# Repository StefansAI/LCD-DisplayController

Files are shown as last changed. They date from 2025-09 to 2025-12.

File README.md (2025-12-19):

<h1 style="text-align: center;">LCD-DisplayController</h1>
<h2 style="text-align: center;">Controller board to display 2 and 4 lines on LCD modules</h2>
<br>
<div style="text-align: center;">
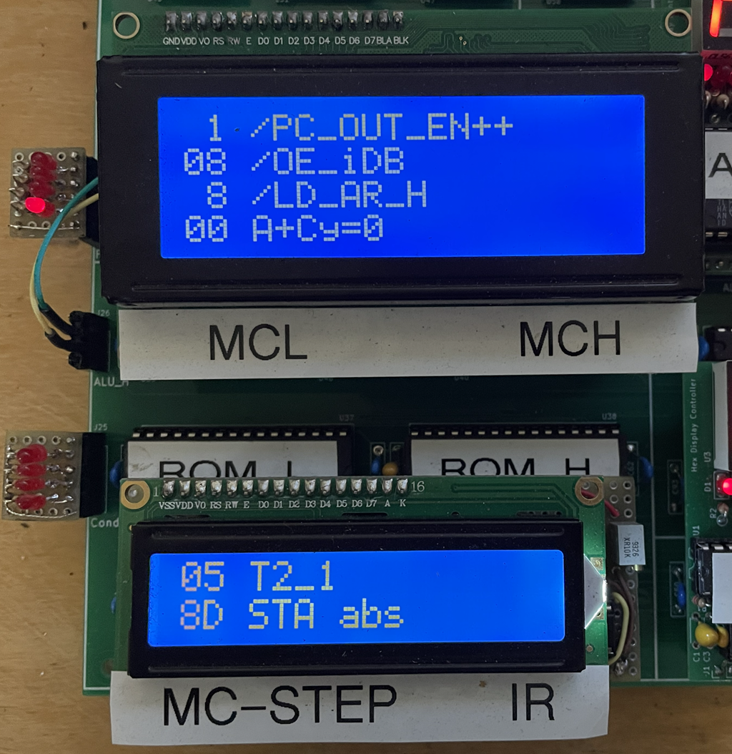
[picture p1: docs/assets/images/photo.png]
  
</div>
<br>
The <a href="https://github.com/StefansAI/TTL-6510-Computer">TTL 6510 computer.</a> was designed with connectors for plugging in <a href="https://github.com/StefansAI/HexDisplayController">HexDisplayControllers</a> for displaying register contents etc. Originally these hex displays were used for the micro code steps, instruction register and micro code outputs. Instead of looking up the meaning of instruction codes or the micro code bit group meanings, I decided to switch to multi line displays I had laying around.<br>
The instruction code and micro step counter can be displayed on a 2 line LCD text display module, while the 4 micro step signal groups can better be displayed on a 4 line LCD text display module. 
<br>
<br>
<div style="text-align: center;">
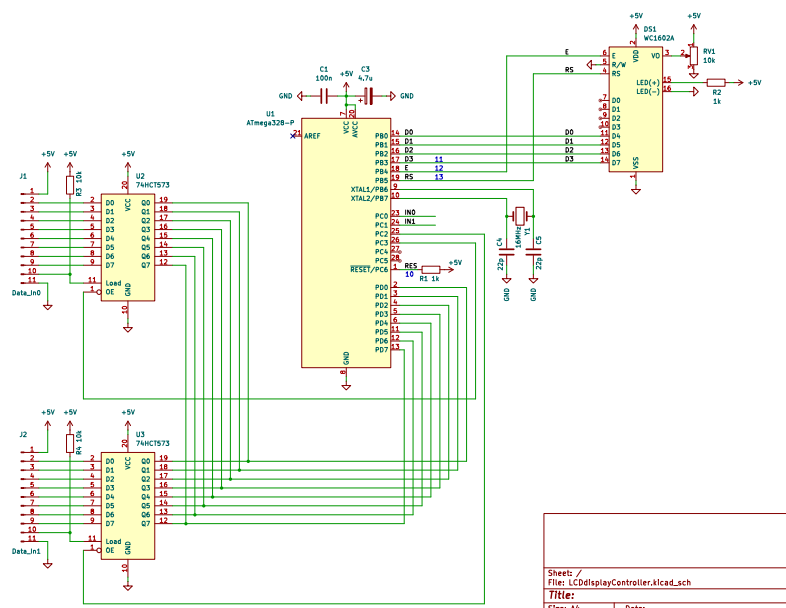
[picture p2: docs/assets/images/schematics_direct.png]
  
</div>
<br>
Both modules can be interfaced in the same way, so the schematics for both can be the same. There are two 8-bit ports to read in from. Since the Arduino processor doesn't have enough pins for both, they are multiplexed to one 8-bit bus.<br>
The LCD module is connected via 4 bit databus as in the example codes for the the Arduino. Then it only needs the resistor for the back light and a potentiometer for the contrast.<br>
<br>
<br>
<div style="text-align: center;">
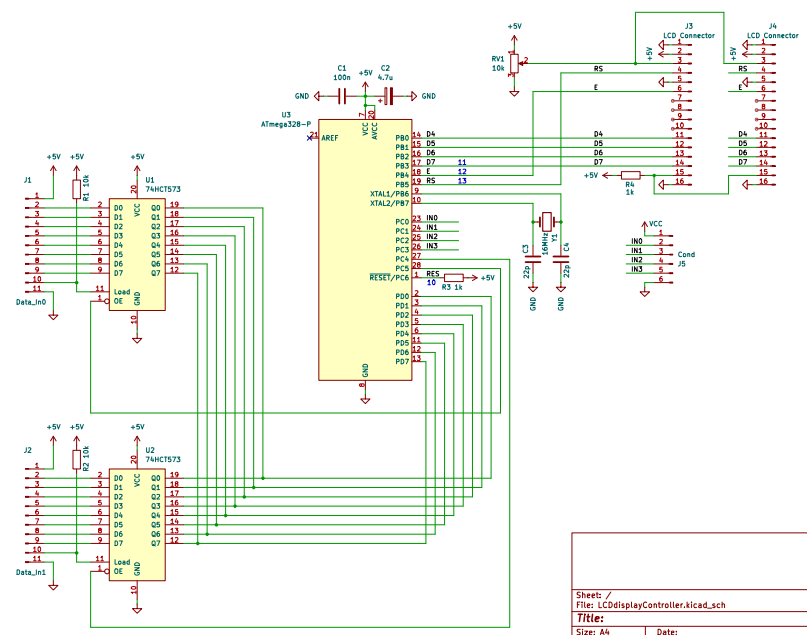
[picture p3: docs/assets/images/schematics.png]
  
</div>
<br>
The boards in the picture above are hand wired, but to make it nicer and repeatable there needs to be a PCB layout for both cases. The two LCD modules 16x2 and 20x4 have different dimensions and so I changed the design for 2 connectors in parallel, one to be used for the 16x2 module and the other to be used by the 20x4 module.<br>
Another 4-bit header was added to include reading in more bits that are currently wired to single LEDs on the side of the <a href="https://github.com/StefansAI/TTL-6510-Computer">TTL 6510 computer</a> board Rev A. Rev B is now routed to those headers.
<br>
<br>
<div style="text-align: center;">
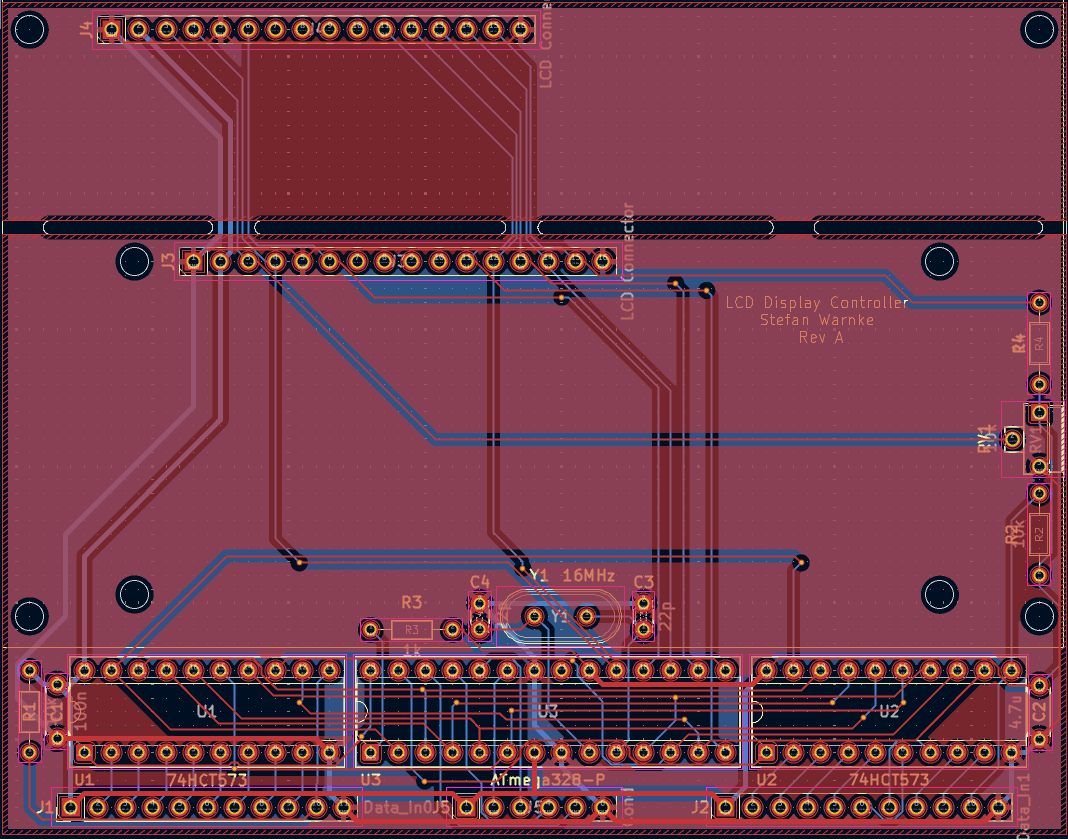
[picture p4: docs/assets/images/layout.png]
  
</div>
<br>
The layout is made to plug in the two different sizes of LCD modules and to break off the part only needed for the larger module. The PCB had been made at <a href="www.PCBway.com">PCBway.</a> It was easy to upload the gerbers, get a quote and order the samples. The shipment took just few days.
<br>
<br>
<div style="text-align: center;">
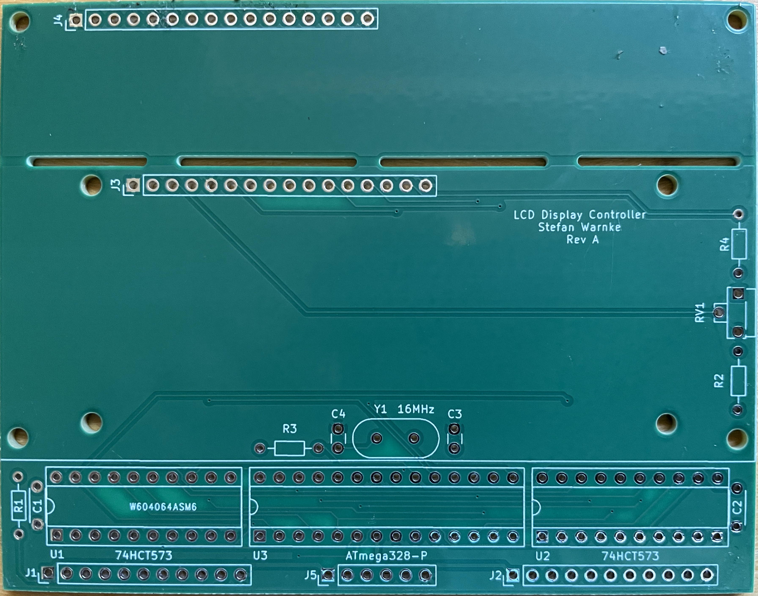
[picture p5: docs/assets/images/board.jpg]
  
</div>
<br>
The blank board as it came from <a href="www.PCBway.com">PCBway.</a> The quality was good and it worked right away as usual.
<br>
<br>
<div style="text-align: center;">
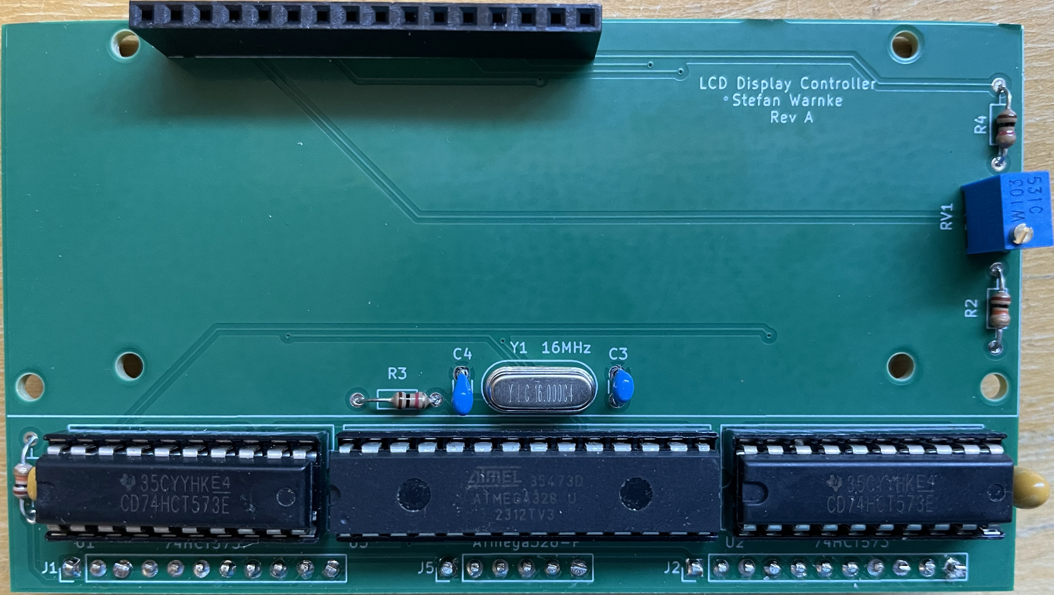
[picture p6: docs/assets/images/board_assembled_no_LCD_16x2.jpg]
  
</div>
<br>
Board broken off and assembled for LCD 16x2.
<br>
<br>
<div style="text-align: center;">
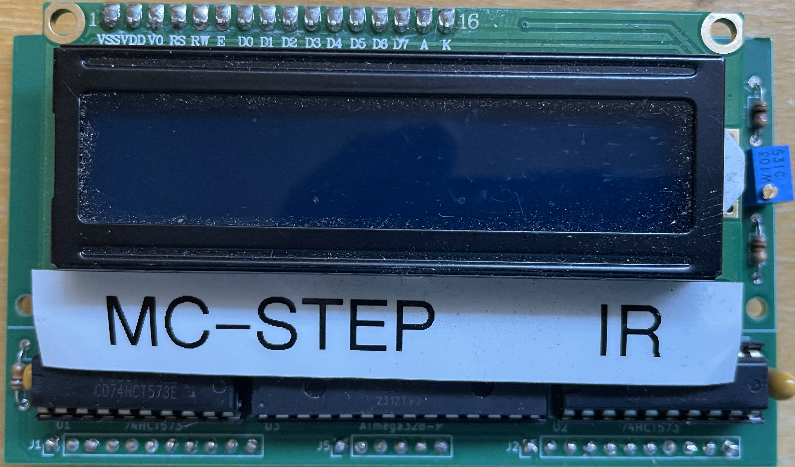
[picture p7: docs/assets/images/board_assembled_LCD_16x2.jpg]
  
</div>
<br>
Board fully assembled with LCD 16x2.
<br>
<br>
<div style="text-align: center;">
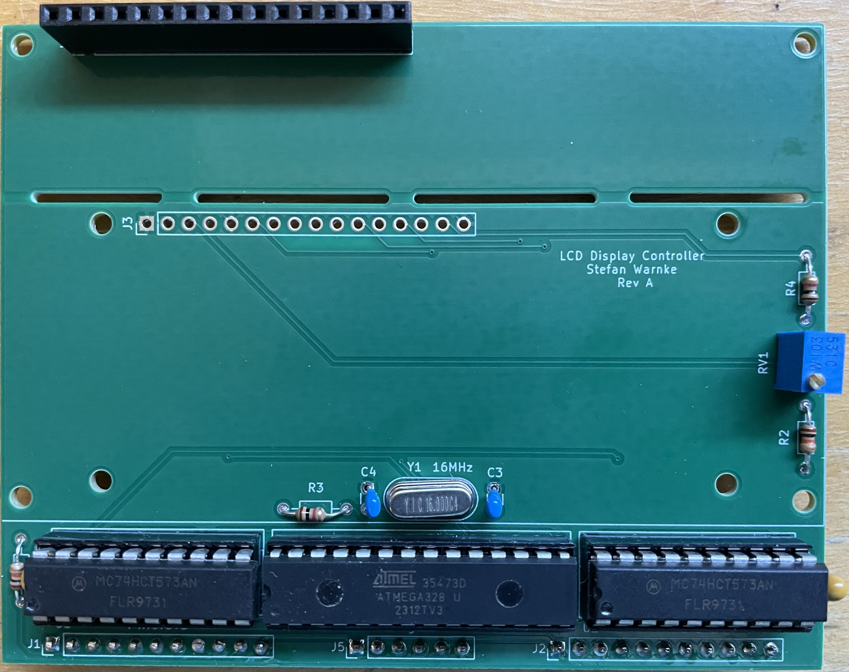
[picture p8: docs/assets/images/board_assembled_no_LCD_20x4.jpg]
  
</div>
<br>
Board assembled for LCD 20x4.
<br>
<br>
<div style="text-align: center;">
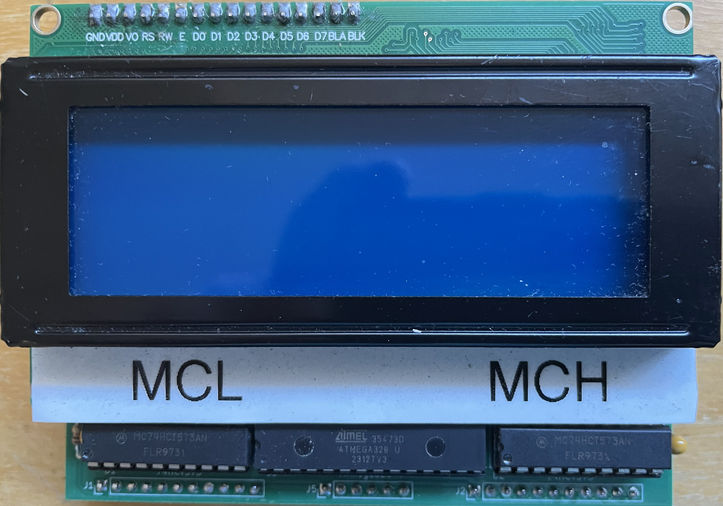
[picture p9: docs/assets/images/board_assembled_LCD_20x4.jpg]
  
</div>
<br>
Board fully assembled with LCD 20x4.
<br>
<br>
<div style="text-align: center;">
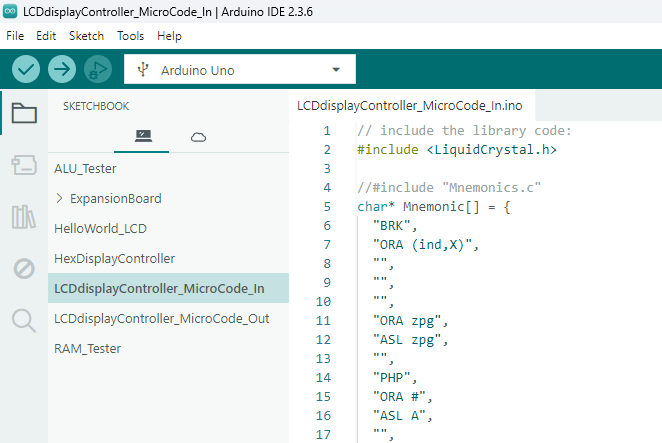
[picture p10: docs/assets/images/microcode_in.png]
  
</div>
<br>
Similar to the <a href="https://github.com/StefansAI/HexDisplayController">HexDisplayController</a>, the processor code is written in the Arduino IDE, then programmed onto the UNO R3 board. The processor is then removed from the UNO board and plugged into the LCD board. Here is a screenshot of the MicroCode_In version containing the 6502 instruction strings.
<br>
<br>
<div style="text-align: center;">
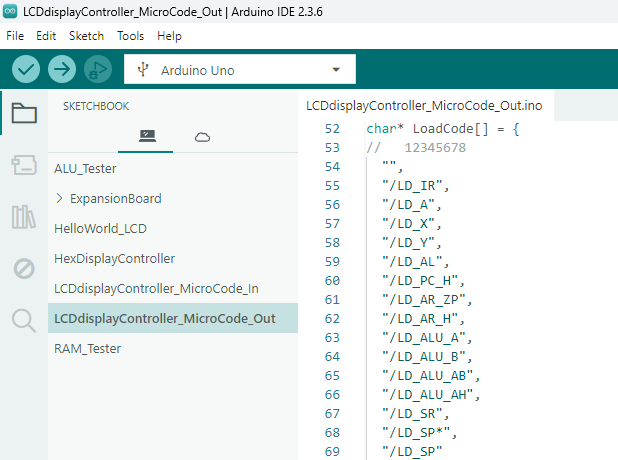
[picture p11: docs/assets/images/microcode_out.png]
  
</div>
<br>
The second screenshot shows string definitions for the micro code output signals.<br>

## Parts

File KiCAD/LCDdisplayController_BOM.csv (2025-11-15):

Reference | Qty | Value | DNP | Exclude from BOM | Exclude from Board | Footprint | Datasheet | OrderInfo | OrderInfo2
C1 | 1 | 100n |  |  |  | Capacitor_THT:C_Disc_D4.3mm_W1.9mm_P5.00mm | ~ | https://www.digikey.com/en/products/detail/kemet/C320C104M5R5TA/3726028
C2 | 1 | 4.7u |  |  |  | Capacitor_THT:C_Disc_D4.3mm_W1.9mm_P5.00mm | ~ | https://www.digikey.com/en/products/detail/kyocera-avx/TAP475M010SCS/1472017
C3,C4 | 2 | 22p |  |  |  | Capacitor_THT:C_Disc_D3.0mm_W1.6mm_P2.50mm | ~ | https://www.digikey.com/en/products/detail/tdk-corporation/FG28C0G1H220JNT06/5803099
DS1 | 1 | WC1602A |  | Excluded from BOM |  | Display:WC1602A | http://www.wincomlcd.com/pdf/WC1602A-SFYLYHTC06.pdf | https://www.amazon.com/gp/product/B0BFDGTPBP/ref=ox_sc_act_title_1?smid=A2RJ79XBQX6W3M&th=1 | https://www.amazon.com/dp/B0BFDDZ49T?ref=ppx_yo2ov_dt_b_fed_asin_title&th=1
J1 | 1 | Data_In0 |  |  |  | Connector_PinHeader_2.54mm:PinHeader_1x11_P2.54mm_Vertical | ~ | https://www.digikey.com/en/products/detail/harwin-inc/M20-9771146/3920928
J2 | 1 | Data_In1 |  |  |  | Connector_PinHeader_2.54mm:PinHeader_1x11_P2.54mm_Vertical | ~ | https://www.digikey.com/en/products/detail/harwin-inc/M20-9771146/3920928
J3,J4 | 2 | LCD Connector |  |  |  | Connector_PinHeader_2.54mm:PinHeader_1x16_P2.54mm_Vertical | ~ | https://www.digikey.com/en/products/detail/w%C3%BCrth-elektronik/61301611821/6137797
J5 | 1 | Cond |  |  |  | Connector_PinHeader_2.54mm:PinHeader_1x06_P2.54mm_Vertical | ~ | https://www.digikey.com/en/products/detail/metz-connect-usa-inc/PR20206VBNN/12342874
R1,R2 | 2 | 10k |  |  |  | Resistor_THT:R_Axial_DIN0204_L3.6mm_D1.6mm_P7.62mm_Horizontal | ~ | https://www.digikey.com/en/products/detail/stackpole-electronics-inc/CF18JT1K00/1741612
R3,R4 | 2 | 1k |  |  |  | Resistor_THT:R_Axial_DIN0204_L3.6mm_D1.6mm_P7.62mm_Horizontal | ~ | https://www.digikey.com/en/products/detail/stackpole-electronics-inc/CF18JT1K00/1741612
RV1 | 1 | 10k |  |  |  | Potentiometer_THT:Potentiometer_Runtron_RM-063_Horizontal | ~ | https://www.digikey.com/en/products/detail/bourns-inc/PV37W103C01B00/666597
U1,U2 | 2 | 74HCT573 |  |  |  | Package_DIP:DIP-20_W7.62mm_Socket | 74xx/74hc573.pdf | https://www.digikey.com/en/products/detail/texas-instruments/CD74HCT573E/38717
U3 | 1 | ATmega328-P |  |  |  | Package_DIP:DIP-28_W7.62mm_Socket | http://ww1.microchip.com/downloads/en/DeviceDoc/ATmega328_P%20AVR%20MCU%20with%20picoPower%20Technology%20Data%20Sheet%2040001984A.pdf | https://www.digikey.com/en/products/detail/microchip-technology/ATMEGA328-PU/2271026
Y1 | 1 | 16MHz |  |  |  | Crystal:Crystal_HC49-U_Vertical | ~ | https://www.digikey.com/en/products/detail/yic/16M20P2-49US/15648595
 | 2 | DIP-20_W7.62mm_Socket |  |  |  |  |  | https://www.digikey.com/en/products/detail/on-shore-technology-inc/ED20DT/4147598
 | 1 | DIP-28_W7.62mm_Socket |  |  |  |  |  | https://www.digikey.com/en/products/detail/on-shore-technology-inc/ED281DT/4147600

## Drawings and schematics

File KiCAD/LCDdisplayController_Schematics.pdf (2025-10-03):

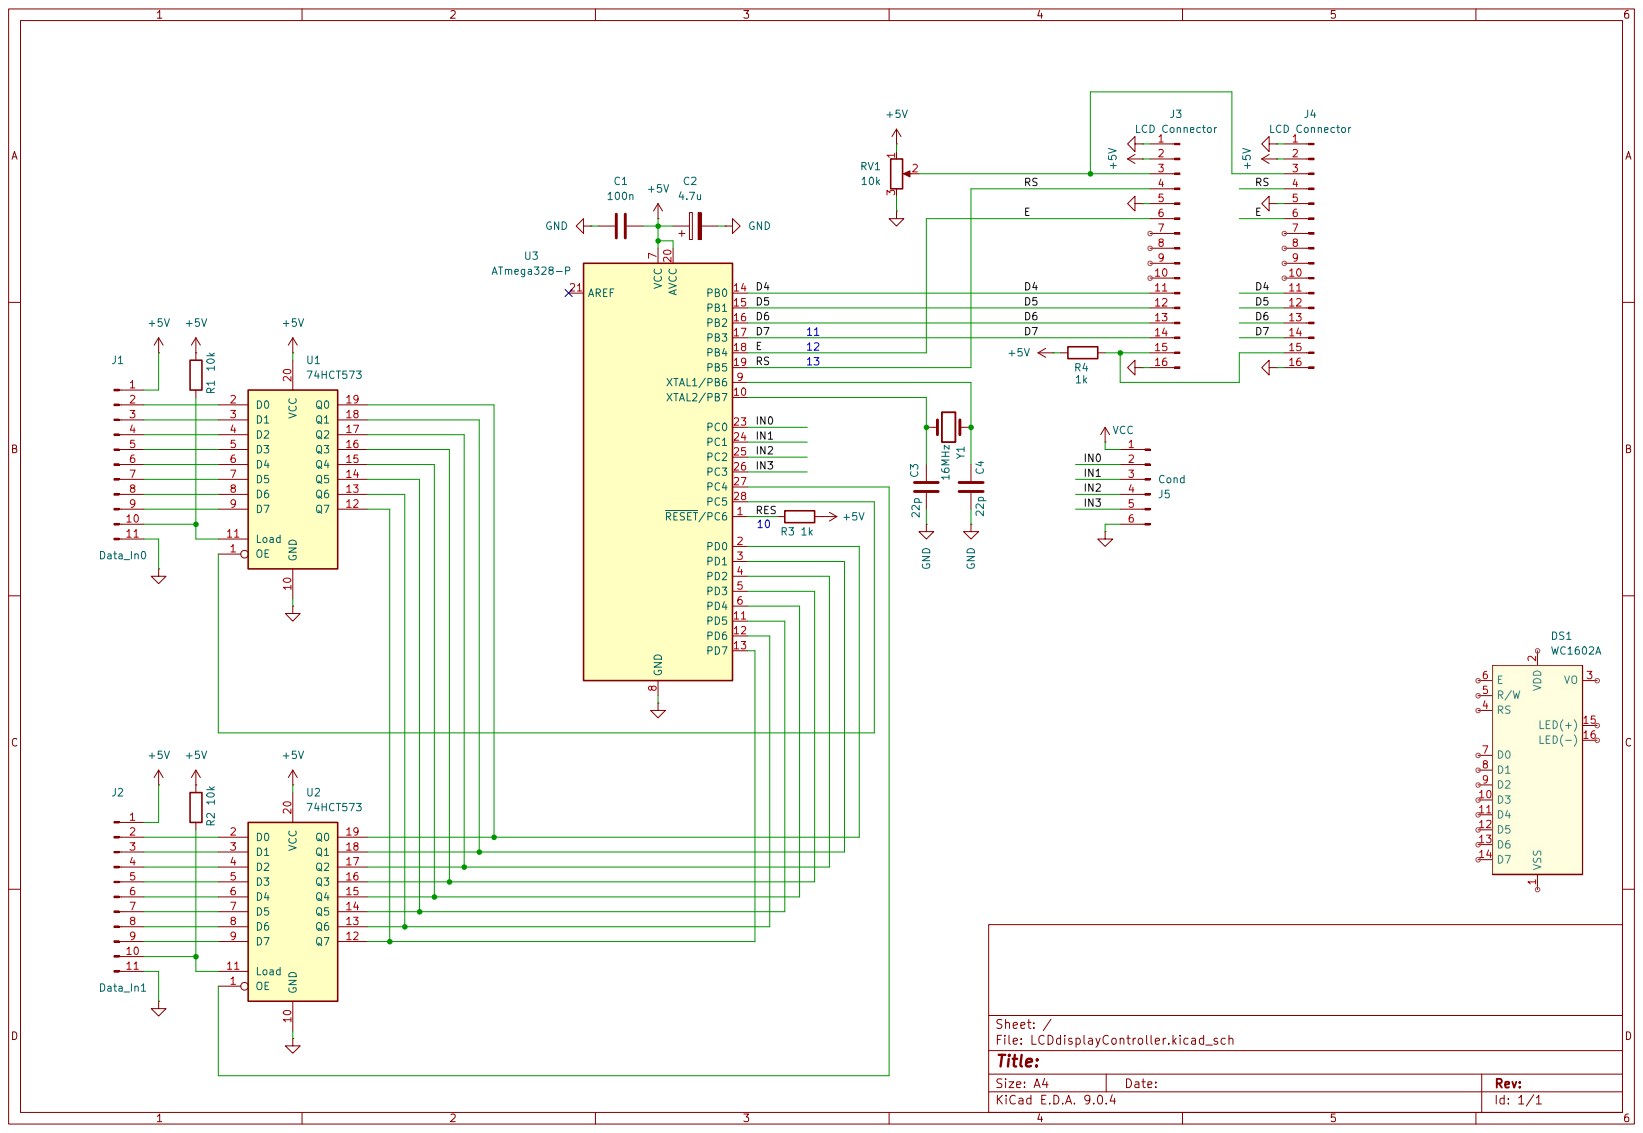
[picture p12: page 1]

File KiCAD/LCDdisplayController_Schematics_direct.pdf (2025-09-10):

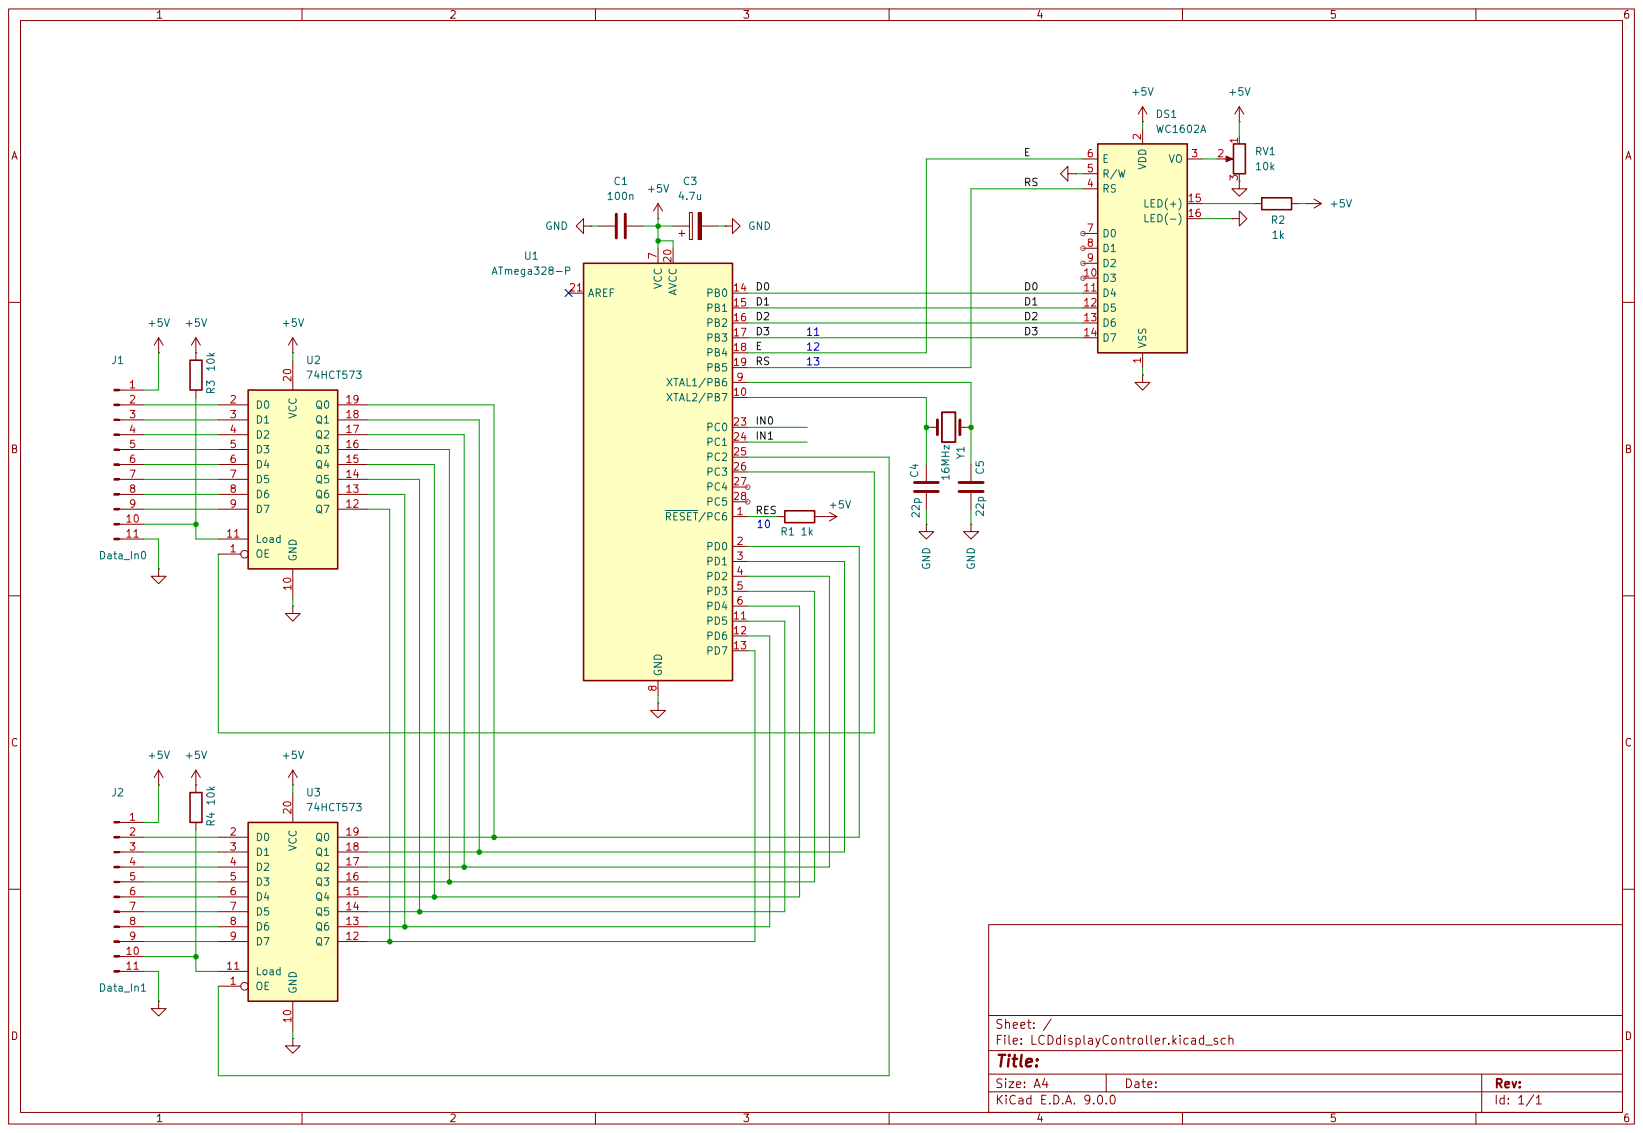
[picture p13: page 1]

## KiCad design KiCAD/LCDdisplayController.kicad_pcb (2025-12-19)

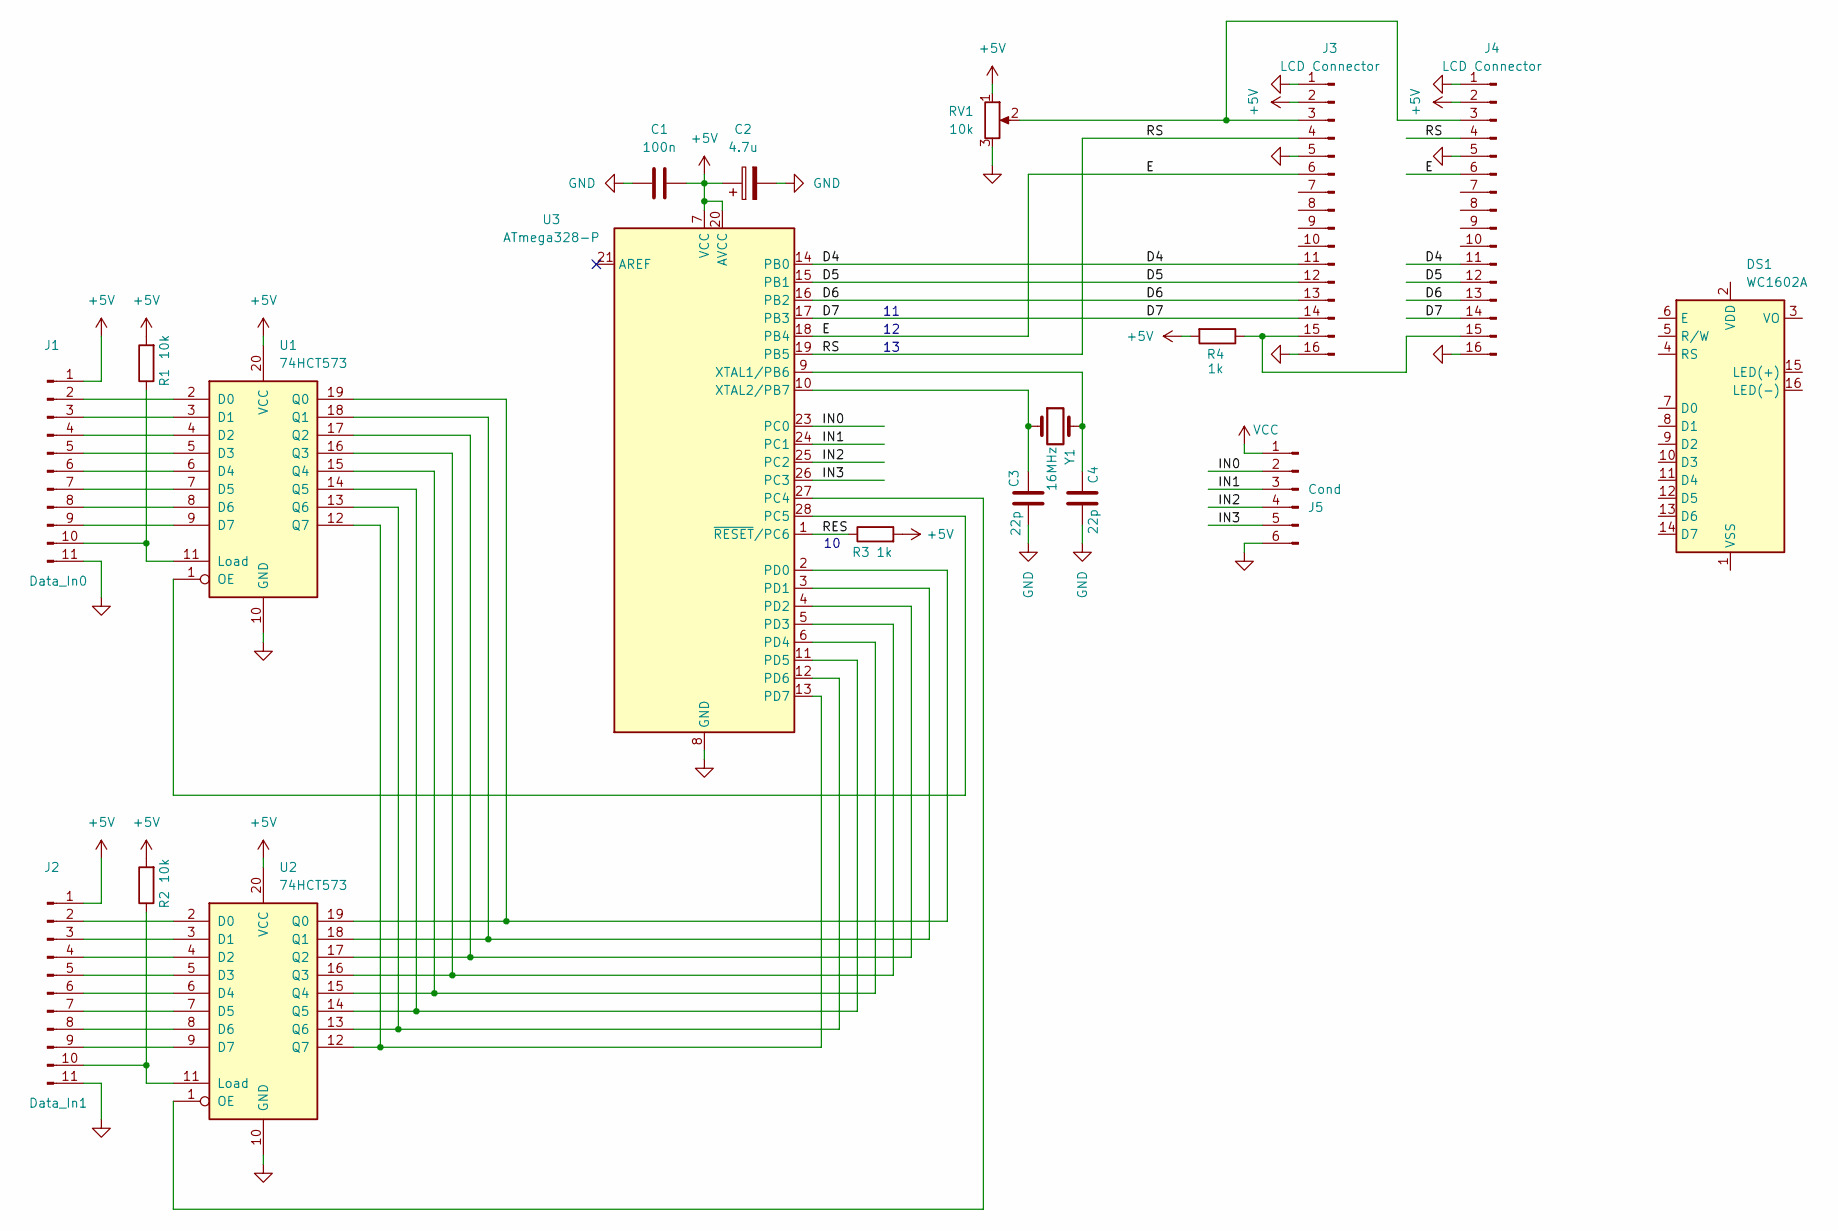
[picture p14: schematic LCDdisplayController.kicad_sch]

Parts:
C1: 100n; C_Disc_D4.3mm_W1.9mm_P5.00mm
C2: 4.7u; C_Disc_D4.3mm_W1.9mm_P5.00mm
C3, C4: 22p; C_Disc_D3.0mm_W1.6mm_P2.50mm
DS1: WC1602A
J1: Data_In0; PinHeader_1x11_P2.54mm_Vertical
J2: Data_In1; PinHeader_1x11_P2.54mm_Vertical
J3, J4: LCD Connector; PinHeader_1x16_P2.54mm_Vertical
J5: Cond; PinHeader_1x06_P2.54mm_Vertical
R1, R2: 10k; R_Axial_DIN0204_L3.6mm_D1.6mm_P7.62mm_Horizontal
R3, R4: 1k; R_Axial_DIN0204_L3.6mm_D1.6mm_P7.62mm_Horizontal
RV1: 10k; Potentiometer_Runtron_RM-063_Horizontal
U1, U2: 74HCT573; DIP-20_W7.62mm_Socket
U3: ATmega328-P; DIP-28_W7.62mm_Socket
Y1: 16MHz; Crystal_HC49-U_Vertical

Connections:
/D4: J3.11, J4.11, U3.14 (PB0)
/D5: J3.12, J4.12, U3.15 (PB1)
/D6: J3.13, J4.13, U3.16 (PB2)
/D7: J3.14, J4.14, U3.17 (PB3)
/E: J3.6, J4.6, U3.18 (PB4)
/IN0: J5.2, U3.23 (PC0)
/IN1: J5.3, U3.24 (PC1)
/IN2: J5.4, U3.25 (PC2)
/IN3: J5.5, U3.26 (PC3)
/RES: R3.1, U3.1 (~RESET/PC6)
/RS: J3.4, J4.4, U3.19 (PB5)
GND: C1.1, C2.2, C3.2, C4.2, J1.11, J2.11, J3.1, J3.5, J3.16, J4.1, J4.5, J4.16, J5.6, RV1.3, U1.10 (GND), U2.10 (GND), U3.8 (GND), U3.22 (GND)
unnamed: J1.2, U1.2 (D0)
unnamed: J1.3, U1.3 (D1)
unnamed: J1.4, U1.4 (D2)
unnamed: J1.5, U1.5 (D3)
unnamed: J1.6, U1.6 (D4)
unnamed: J1.7, U1.7 (D5)
unnamed: J1.8, U1.8 (D6)
unnamed: J1.9, U1.9 (D7)
unnamed: J1.10, R1.1, U1.11 (Load)
unnamed: J2.2, U2.2 (D0)
unnamed: J2.3, U2.3 (D1)
unnamed: J2.4, U2.4 (D2)
unnamed: J2.5, U2.5 (D3)
unnamed: J2.6, U2.6 (D4)
unnamed: J2.7, U2.7 (D5)
unnamed: J2.8, U2.8 (D6)
unnamed: J2.9, U2.9 (D7)
unnamed: J2.10, R2.1, U2.11 (Load)
unnamed: J3.3, J4.3, RV1.2
unnamed: J3.15, J4.15, R4.1
unnamed: U1.1 (OE), U3.28 (PC5)
unnamed: U1.19 (Q0), U2.19 (Q0), U3.2 (PD0)
unnamed: U1.18 (Q1), U2.18 (Q1), U3.3 (PD1)
unnamed: U1.17 (Q2), U2.17 (Q2), U3.4 (PD2)
unnamed: U1.16 (Q3), U2.16 (Q3), U3.5 (PD3)
unnamed: U1.15 (Q4), U2.15 (Q4), U3.6 (PD4)
unnamed: U1.14 (Q5), U2.14 (Q5), U3.11 (PD5)
unnamed: U1.13 (Q6), U2.13 (Q6), U3.12 (PD6)
unnamed: U1.12 (Q7), U2.12 (Q7), U3.13 (PD7)
unnamed: U2.1 (OE), U3.27 (PC4)
unnamed: C4.1, U3.9 (XTAL1/PB6), Y1.2
unnamed: C3.1, U3.10 (XTAL2/PB7), Y1.1

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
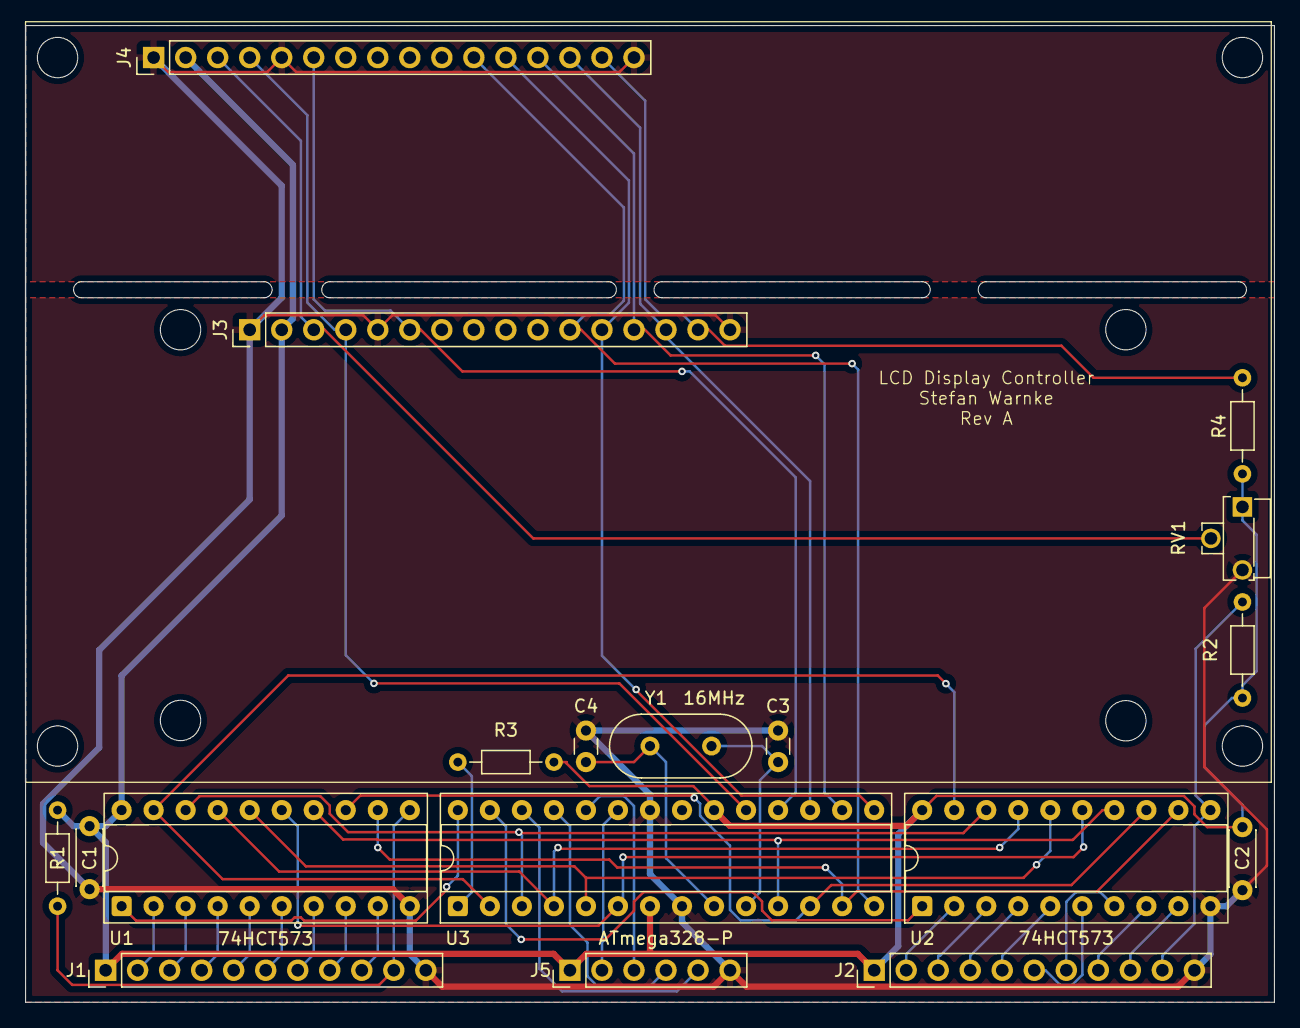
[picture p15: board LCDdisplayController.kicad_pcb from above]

Board: 2 copper layers, 99.1 x 77.5 mm, 18 parts (0 on the bottom side), 45 nets.

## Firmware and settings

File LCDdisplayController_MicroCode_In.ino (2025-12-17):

// include the library code:
#include <LiquidCrystal.h>

// Input data pin definition array
const int DIN[8] = { 0, 1, 2, 3, 4, 5, 6, 7 }; 

// Pin definition for the additional input 0
const int IN[4] = {A0, A1, A2, A3 };

// LCD data output pins
const int LCD_D[4] = { 8, 9, 10, 11 };

// LCD enable pin
const int LCD_E = 12;
// LCD rs pin
const int LCD_RS = 13;

LiquidCrystal lcd(LCD_RS, LCD_E, LCD_D[0], LCD_D[1], LCD_D[2], LCD_D[3]);

// Input buffer enable
const int OE[2] = { 18, 19 };


//#include "Mnemonics.c"
char* Mnemonic[] = {
	"BRK",
	"ORA (ind,X)",
	"",
	"",
	"",
	"ORA zpg",
	"ASL zpg",
	"",
	"PHP",
	"ORA #",
	"ASL A",
	"",
	"",
	"ORA abs",
	"ASL abs",
	"",
	"BPL rel",
	"ORA (ind),Y",
	"",
	"",
	"",
	"ORA zpg,X",
	"ASL zpg,X",
	"",
	"CLC",
	"ORA abs,Y",
	"",
	"",
	"",
	"ORA abs,X",
	"ASL abs,X",
	"",
	"JSR abs",
	"AND (ind,X)",
	"",
	"",
	"BIT zpg",
	"AND zpg",
	"ROL zpg",
	"",
	"PLP",
	"AND #",
	"ROL A",
	"",
	"BIT abs",
	"AND abs",
	"ROL abs",
	"",
	"BMI rel",
	"AND (ind),Y",
	"",
	"",
	"",
	"AND zpg,X",
	"ROL zpg,X",
	"",
	"SEC",
	"AND abs,Y",
	"",
	"",
	"",
	"AND abs,X",
	"ROL abs,X",
	"",
	"RTI",
	"EOR (ind,X)",
	"",
	"",
	"",
	"EOR zpg",
	"LSR zpg",
	"",
	"PHA",
	"EOR #",
	"LSR A",
	"",
	"JMP abs",
	"EOR abs",
	"LSR abs",
	"",
	"BVC rel",
	"EOR (ind),Y",
	"",
	"",
	"",
	"EOR zpg,X",
	"LSR zpg,X",
	"",
	"CLI",
	"EOR abs,Y",
	"",
	"",
	"",
	"EOR abs,X",
	"LSR abs,X",
	"",
	"RTS",
	"ADC (ind,X)",
	"",
	"",
	"",
	"ADC zpg",
	"ROR zpg",
	"",
	"PLA",
	"ADC #",
	"ROR A",
	"",
	"JMP (ind)",
	"ADC abs",
	"ROR abs",
	"",
	"BVS rel",
	"ADC (ind),Y",
	"",
	"",
	"",
	"ADC zpg,X",
	"ROR zpg,X",
	"",
	"SEI",
	"ADC abs,Y",
	"",
	"",
	"",
	"ADC abs,X",
	"ROR abs,X",
	"",
	"",
	"STA (ind,X)",
	"",
	"",
	"STY zpg",
	"STA zpg",
	"STX zpg",
	"",
	"DEY",
	"",
	"TXA",
	"",
	"STY abs",
	"STA abs",
	"STX abs",
	"",
	"BCC rel",
	"STA (ind),Y",
	"",
	"",
	"STY zpg,X",
	"STA zpg,X",
	"STX zpg,Y",
	"",
	"TYA",
	"STA abs,Y",
	"TXS",
	"",
	"",
	"STA abs,X",
	"",
	"",
	"LDY #",
	"LDA (ind,X)",
	"LDX #",
	"",
	"LDY zpg",
	"LDA zpg",
	"LDX zpg",
	"",
	"TAY",
	"LDA #",
	"TAX",
	"",
	"LDY abs",
	"LDA abs",
	"LDX abs",
	"",
	"BCS rel",
	"LDA (ind),Y",
	"",
	"",
	"LDY zpg,X",
	"LDA zpg,X",
	"LDX zpg,Y",
	"",
	"CLV",
	"LDA abs,Y",
	"TSX",
	"",
	"LDY abs,X",
	"LDA abs,X",
	"LDX abs,Y",
	"",
	"CPY #",
	"CMP (ind,X)",
	"",
	"",
	"CPY zpg",
	"CMP zpg",
	"DEC zpg",
	"",
	"INY",
	"CMP #",
	"DEX",
	"",
	"CPY abs",
	"CMP abs",
	"DEC abs",
	"",
	"BNE rel",
	"CMP (ind),Y",
	"",
	"",
	"",
	"CMP zpg,X",
	"DEC zpg,X",
	"",
	"CLD",
	"CMP abs,Y",
	"",
	"",
	"",
	"CMP abs,X",
	"DEC abs,X",
	"",
	"CPX #",
	"SBC (ind,X)",
	"",
	"",
	"CPX zpg",
	"SBC zpg",
	"INC zpg",
	"",
	"INX",
	"SBC #",
	"NOP",
	"",
	"CPX abs",
	"SBC abs",
	"INC abs",
	"",
	"BEQ rel",
	"SBC (ind),Y",
	"",
	"",
	"",
	"SBC zpg,X",
	"INC zpg,X",
	"",
	"SED",
	"SBC abs,Y",
	"",
	"",
	"",
	"SBC abs,X",
	"INC abs,X",
	"",
	""
};


// Query all data input bits and return the 8bit data value read from the input chip.
int get_data(int idx)
{
	digitalWrite(OE[idx], LOW);

  int result=0;
  for (int i=0; i<8; i++)
  {
    int value = digitalRead(DIN[i]);
    if (value == HIGH)
      result += 1<<i;    
  }

	digitalWrite(OE[idx], HIGH);
  return result;
}

void write_hex(int x, int y, int code)
{
	  // set up the LCD's number of columns and rows:
  lcd.setCursor(x, y);
  if ((code & 0xF0) == 0)
  {
    lcd.print(0);
    lcd.setCursor(x+1, y);
  }

  // Print a message to the LCD.
  lcd.print(code,HEX);

  // set up the LCD's number of columns and rows:
  lcd.setCursor(x+3, y);
}


// Variable to capture the input data from the 74HCT574 or 74HCT573
int opcode = 0;
int microstep = 0;
int flags = 0;


// Initialization function called before the loop
void setup() {
	// put your setup code here, to run once:
	for (int i = 0; i<4; i++)
 		pinMode(IN[i], INPUT);
 
	for (int i = 0; i<8; i++)
  	pinMode(DIN[i], INPUT);

  for (int i=0; i<2; i++)
	{
  	pinMode(OE[i], OUTPUT);
  	digitalWrite(OE[i], HIGH);
	}

  // set up the LCD's number of columns and rows:
  lcd.begin(16, 2);
}

char buffer[32];

// Main loop function
void loop() {
  // put your main code here, to run repeatedly:
  opcode = get_data(1);
  microstep = get_data(0);
  
	sprintf(buffer,"%s                ",Mnemonic[opcode]);
	buffer[13]= 0;

	write_hex(0, 0, microstep);

	lcd.print("T");
	lcd.print(microstep >> 1);
	lcd.print("_");
	lcd.print(microstep & 1);
  lcd.print("  ");

	lcd.setCursor(12, 0);

	if (digitalRead(IN[3]) == 0)
		lcd.print("e");
	else
		lcd.print("E");

	if (digitalRead(IN[2]) == 0)
		lcd.print("s");
	else
		lcd.print("S");

	if (digitalRead(IN[1]) == 0)
		lcd.print("h");
	else
		lcd.print("H");

	if (digitalRead(IN[0]) == 0)
		lcd.print("f");
	else
		lcd.print("F");

 	write_hex(0, 1, opcode);

   // Print a message to the LCD.
  lcd.print(buffer);

  delay(250);
}

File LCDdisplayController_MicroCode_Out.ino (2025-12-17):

// include the library code:
#include <LiquidCrystal.h>

// Input data pin definition array
const int DIN[8] = { 0, 1, 2, 3, 4, 5, 6, 7 }; 

// Pin definition for the additional input 0
const int IN[4] = {A0, A1, A2, A3 };

// LCD data output pins
const int LCD_D[4] = { 8, 9, 10, 11 };

// LCD enable pin
const int LCD_E = 12;
// LCD rs pin
const int LCD_RS = 13;

LiquidCrystal lcd(LCD_RS, LCD_E, LCD_D[0], LCD_D[1], LCD_D[2], LCD_D[3]);

// Input buffer enable
const int OE[2] = { 18, 19 };

char* AddrEn[] = {
//   12345678
	"/PC_OUT_EN",
	"/PC_OUT_EN++",
	"/AR_OUT_EN",
	"/AR_OUT_EN++",
	"/AR_OUT_EN_WR",
	"/AR_OUT_EN_WR++",
	"/SP_OUT_EN",
	"/SP_OUT_EN_WR"
};

char* OutEn[] = {
//   12345678
	"",
	"none_1",
	"none_2",
	"none_3",
	"none_4",
	"none_5",
	"none_6",
	"none_7",
	"/OE_iDB",
	"/OE_iDB_LD_SP",
	"/OE_A_BCD",
	"/OE_A",
	"/OE_X",
	"/OE_Y",
	"/OE_SP",
	"/OE_SR",
	"/OE_PC_H",
	"/OE_PC_L",
	"/OE_PC_L_BR",
	"/OE_BRKL",
	"/OE_SIX_L",
	"/OE_SIX_H",
	"/CH_SR",
	"/ACK_EXC",
	"/OE_ALU",
	"/OE_ALU_NZ",
	"/OE_ALU_NZC",
	"/OE_ALU_NZCV",
	"/OE_ALU_SH",
	"/OE_ALU_HDCY",
	"/OE_ALU_FDCY",
	"/OE_ALU_CY"
};

char* LoadCode[] = {
//   12345678
	"",
	"/LD_IR",
	"/LD_A",
	"/LD_X",
	"/LD_Y",
	"/LD_AL",
	"/LD_PC_H",
	"/LD_AR_ZP",
	"/LD_AR_H",
	"/LD_ALU_A",
	"/LD_ALU_B",
	"/LD_ALU_AB",
	"/LD_ALU_AH",
	"/LD_SR",
	"/LD_SP*",
	"/LD_SP"
};

char* AluCode[] = {
//   12345678
	"A+Cy",
	"(A|B)+Cy",
	"(A|!B)+Cy",
	"-1+Cy",
	"A+(A&/B)+Cy",
	"(A|B)+(A&!B)+Cy",
	"A-B-!Cy",
	"A&!B",
	"A+(A&B)+Cy",
	"A+B+Cy",
	"(A|!B)+(A&B)+Cy",
	"(A&B)-!Cy",
	"A+A+Cy",
	"(A|B)+A+Cy",
	"(A|!B)+A+Cy",
	"A-!Cy",
	"!A",
	"A|!B",
	"A&!B",
	"0",
	"A&!B",
	"!B",
	"A^B",
	"A&!B",
	"!A|B",
	"A^!B",
	"B",
	"A&B",
	"1",
	"A|!B",
	"A|B",
	"A"
};

// Query all data input bits and return the 8bit data value read from the input chip.
int get_data(int idx)
{
  digitalWrite(OE[idx], LOW);

  int result=0;
  for (int i=0; i<8; i++)
  {
    int value = digitalRead(DIN[i]);
    if (value == HIGH)
      result += 1<<i;    
  }

  digitalWrite(OE[idx], HIGH);
  return result;
}

// Variable to capture the input data from the 74HCT574 or 74HCT573
int addr_en = 0;
int out_en = 0;
int load_code = 0;
int alu_code = 0;
int cy_in = 0;


// Initialization function called before the loop
void setup() {
	// put your setup code here, to run once:
		for (int i = 0; i<4; i++)
 		pinMode(IN[i], INPUT);

	for (int i = 0; i<8; i++)
  	pinMode(DIN[i], INPUT_PULLUP);

  for (int i=0; i<2; i++)
	{
  	pinMode(OE[i], OUTPUT);
  	digitalWrite(OE[i], HIGH);
	}

  // set up the LCD's number of columns and rows:
  lcd.begin(20, 4);
}

char buffer[64];
                 //12345678901234567890
char* sformat = "%s                     ";

// Main loop function
void loop() {
  // put your main code here, to run repeatedly:
  int a = get_data(0);
  int b = get_data(1);

  addr_en = a & 0x07;
  out_en = (a >> 3) & 0x1F;
  load_code = b & 0x0F;
  alu_code = (b >> 4) & 0x0F;
  
  if (digitalRead(IN[1]) == HIGH)
		alu_code |= 1<<4;

  if (digitalRead(IN[2]) == HIGH)
		cy_in = 0;
  else
		cy_in = 1;
								  
  lcd.setCursor(1, 0);
	lcd.print(addr_en);
  lcd.setCursor(3, 0);
	sprintf(buffer,sformat,AddrEn[addr_en]);
	buffer[16]= 0;
  lcd.print(buffer);

  lcd.setCursor(0, 1);
  lcd.print(out_en >> 4);
 	lcd.print(out_en & 0xF, HEX);
  lcd.setCursor(3, 1);
	sprintf(buffer,sformat,OutEn[out_en]);
	buffer[16]= 0;
  lcd.print(buffer);

  lcd.setCursor(1, 2);
 	lcd.print(load_code, HEX);
  lcd.setCursor(3, 2);
 	sprintf(buffer,sformat,LoadCode[load_code]);
	buffer[16]= 0;
  lcd.print(buffer);

  lcd.setCursor(0, 3);
 	lcd.print(alu_code >> 4);
	lcd.print(alu_code & 0xF, HEX);
  lcd.setCursor(3, 3);
	sprintf(buffer,sformat,AluCode[alu_code]);
	buffer[16]= 0;
  lcd.print(buffer);

  if ((alu_code >> 4) == 0)
	{
		 lcd.setCursor(strlen(AluCode[alu_code])+3, 3);
		 lcd.print("=");
		 lcd.print(cy_in);
	}

  delay(250);
}

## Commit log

2025-09-10 Initial Check-In
    [LCDdisplayController.kicad_pcb, LCDdisplayController.kicad_sch]
2025-10-03 Updated README and design files
    [LCDdisplayController.kicad_pcb, LCDdisplayController.kicad_sch]
2025-11-15 Updates of KiCad files and README
    [LCDdisplayController-B_Cu.gbr, LCDdisplayController-B_Mask.gbr, LCDdisplayController-B_Paste.gbr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]
2025-12-13 Updating Fab files
    [LCDdisplayController-B_Cu.gbr, LCDdisplayController-B_Mask.gbr, LCDdisplayController-B_Paste.gbr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]
2025-12-19 Some corrections
    [LCDdisplayController.kicad_pcb]
